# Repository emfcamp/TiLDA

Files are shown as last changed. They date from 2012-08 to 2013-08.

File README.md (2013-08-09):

TiLDA documentation
===================

This repository contains documentation, schematics, and libraries for use with TiLDA.
For example code, see the smaller "source" submodule.

Guides
======

* [Archived docs from 2012](http://wiki-archive.emfcamp.org/2012/articles/b/a/d/Badge.html)
* [Example source code](https://github.com/emfcamp/TiLDA-source)

* [Arduino Guide](http://arduino.cc/en/Guide/ArduinoLeonardo)
* [Getting started with the nRF24L01+](http://maniacbug.wordpress.com/2011/11/02/getting-started-rf24/)

Initialising
------------

    git clone --recursive https://github.com/emfcamp/TiLDA

or

    git clone git@github.com:emfcamp/TiLDA
    cd TiLDA
    git submodule update --init

For building instructions, please see the sample source submodule:

* [TiLDA-source](https://github.com/emfcamp/TiLDA-source)

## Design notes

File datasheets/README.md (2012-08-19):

Hardware
========

* [ATmega32U4](http://www.atmel.com/Images/7766s.pdf) processor
* [Arduino Leonardo](http://arduino.cc/en/Main/arduinoBoardLeonardo)

* [MCP73831](http://ww1.microchip.com/downloads/en/DeviceDoc/21984e.pdf) battery controller
* [GP1UX311QS](http://www.adafruit.com/datasheets/GP1UX31QS.pdf) IR receiver
* [TSAL5100](http://www.vishay.com/doc?81007) IR transmitter
* [nRF24L01+](http://www.nordicsemi.com/kor/content/download/2726/34069/file/nRF24L01P_Product_Specification_1_0.pdf) 2.4GHz transceiver
* [nRF240L01+ module](http://dlnmh9ip6v2uc.cloudfront.net/datasheets/Wireless/Nordic/nRF24L01-Chip-v12.pdf) same pinout, but slightly different module

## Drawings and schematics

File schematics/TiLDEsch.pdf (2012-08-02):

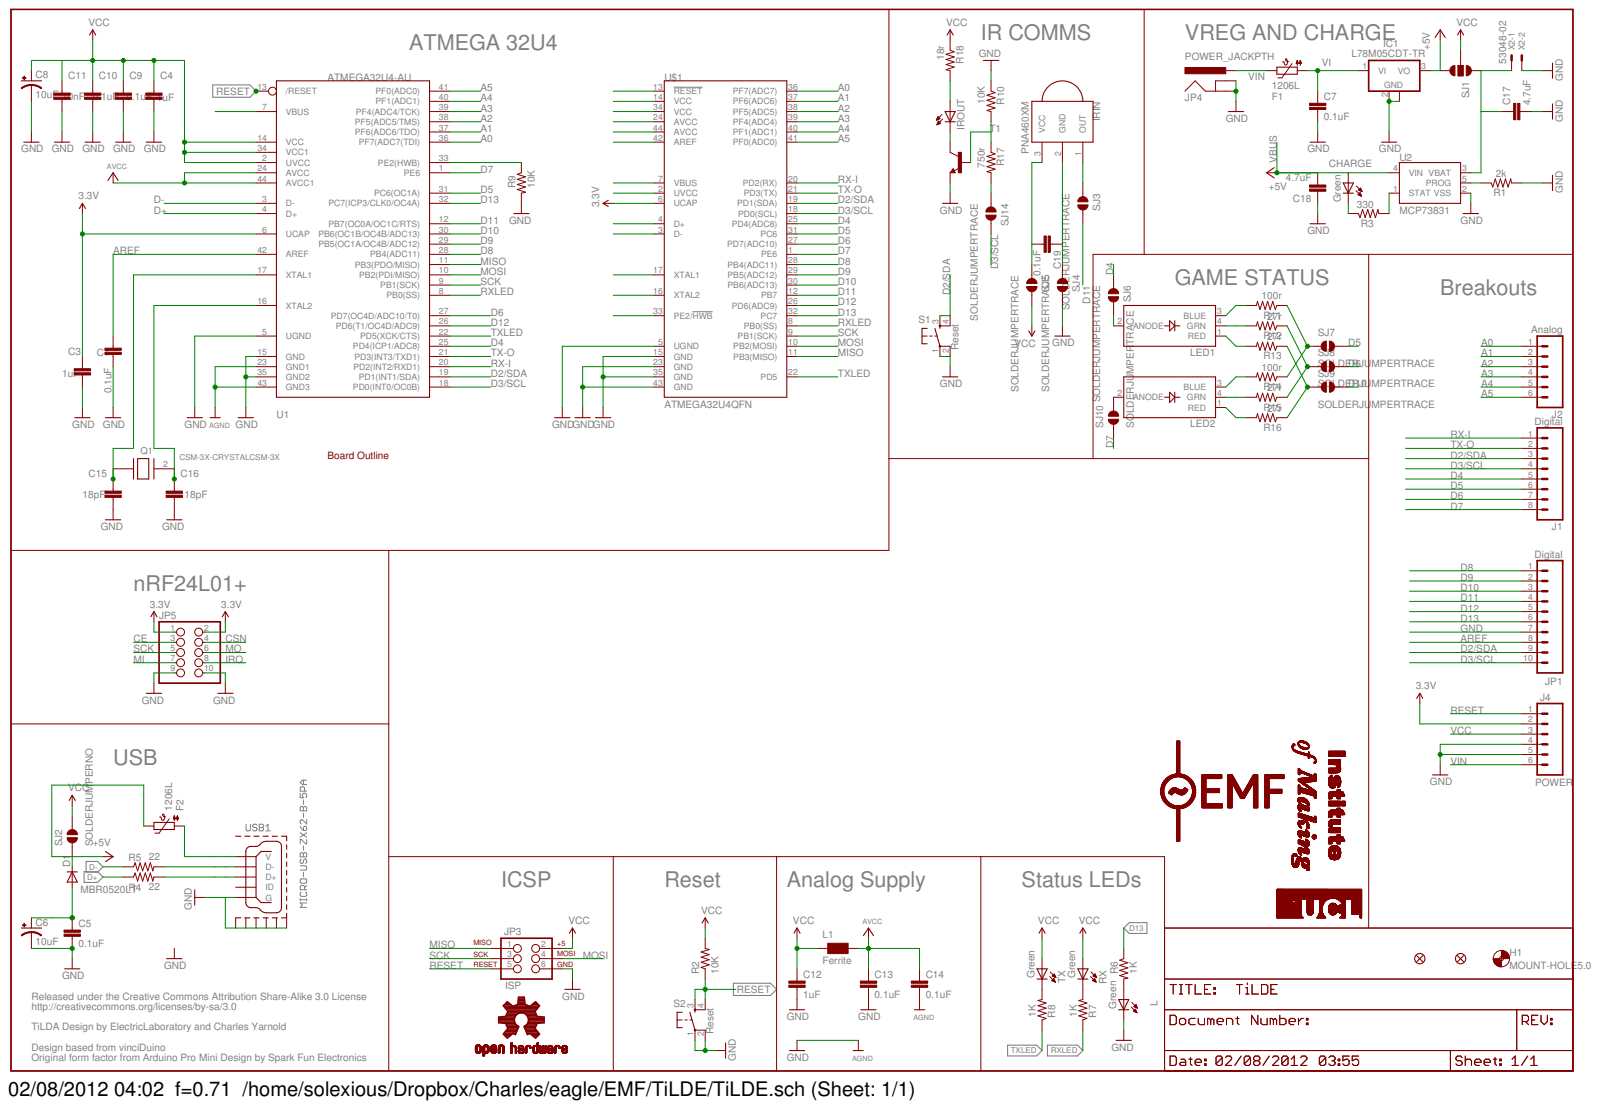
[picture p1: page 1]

GND
Released under the Creative Commons Attribution Share-Alike 3.0 License
http://creativecommons.org/licenses/by-sa/3.0 Original form factor from Arduino Pro Mini Design by Spark Fun Electronics
TiLDA Design by ElectricLaboratory and Charles Yarnold
Design based from vinciDuino
02/08/2012 04:02 f=0.71 /home/solexious/Dropbox/Charles/eagle/EMF/TiLDE/TiLDE.sch (Sheet: 1/1)

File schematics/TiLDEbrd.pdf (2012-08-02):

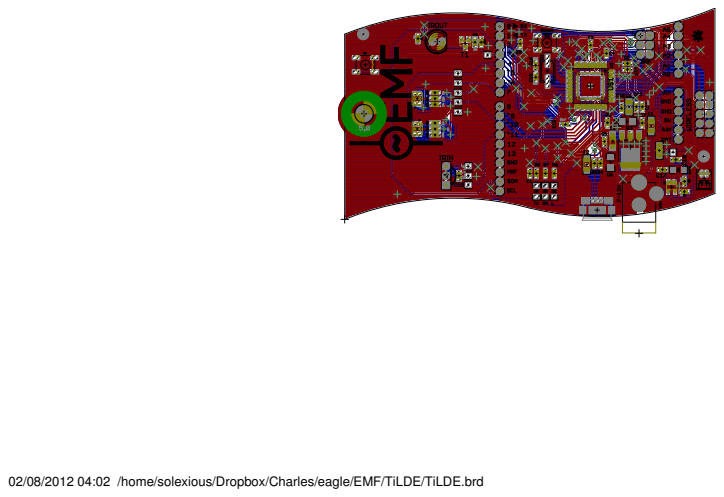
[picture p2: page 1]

02/08/2012 04:02 /home/solexious/Dropbox/Charles/eagle/EMF/TiLDE/TiLDE.brd

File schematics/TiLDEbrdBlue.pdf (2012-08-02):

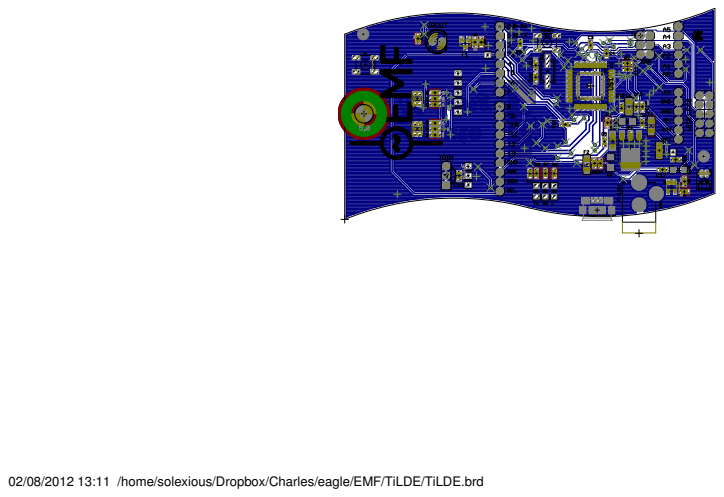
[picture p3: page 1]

02/08/2012 13:11 /home/solexious/Dropbox/Charles/eagle/EMF/TiLDE/TiLDE.brd

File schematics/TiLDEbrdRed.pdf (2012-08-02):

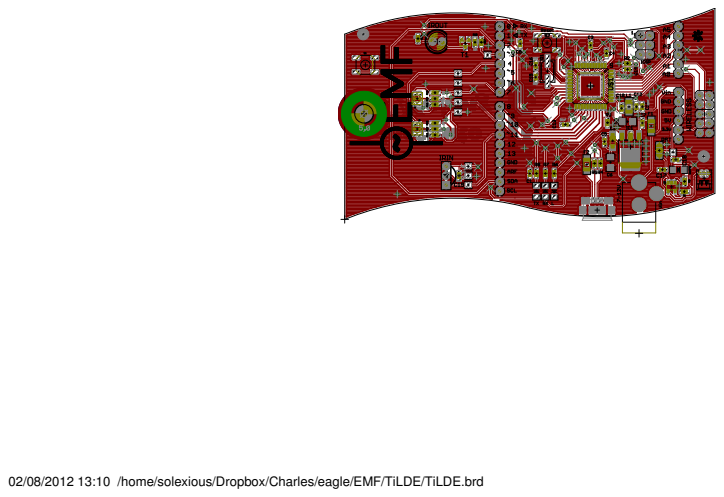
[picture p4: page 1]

02/08/2012 13:10 /home/solexious/Dropbox/Charles/eagle/EMF/TiLDE/TiLDE.brd

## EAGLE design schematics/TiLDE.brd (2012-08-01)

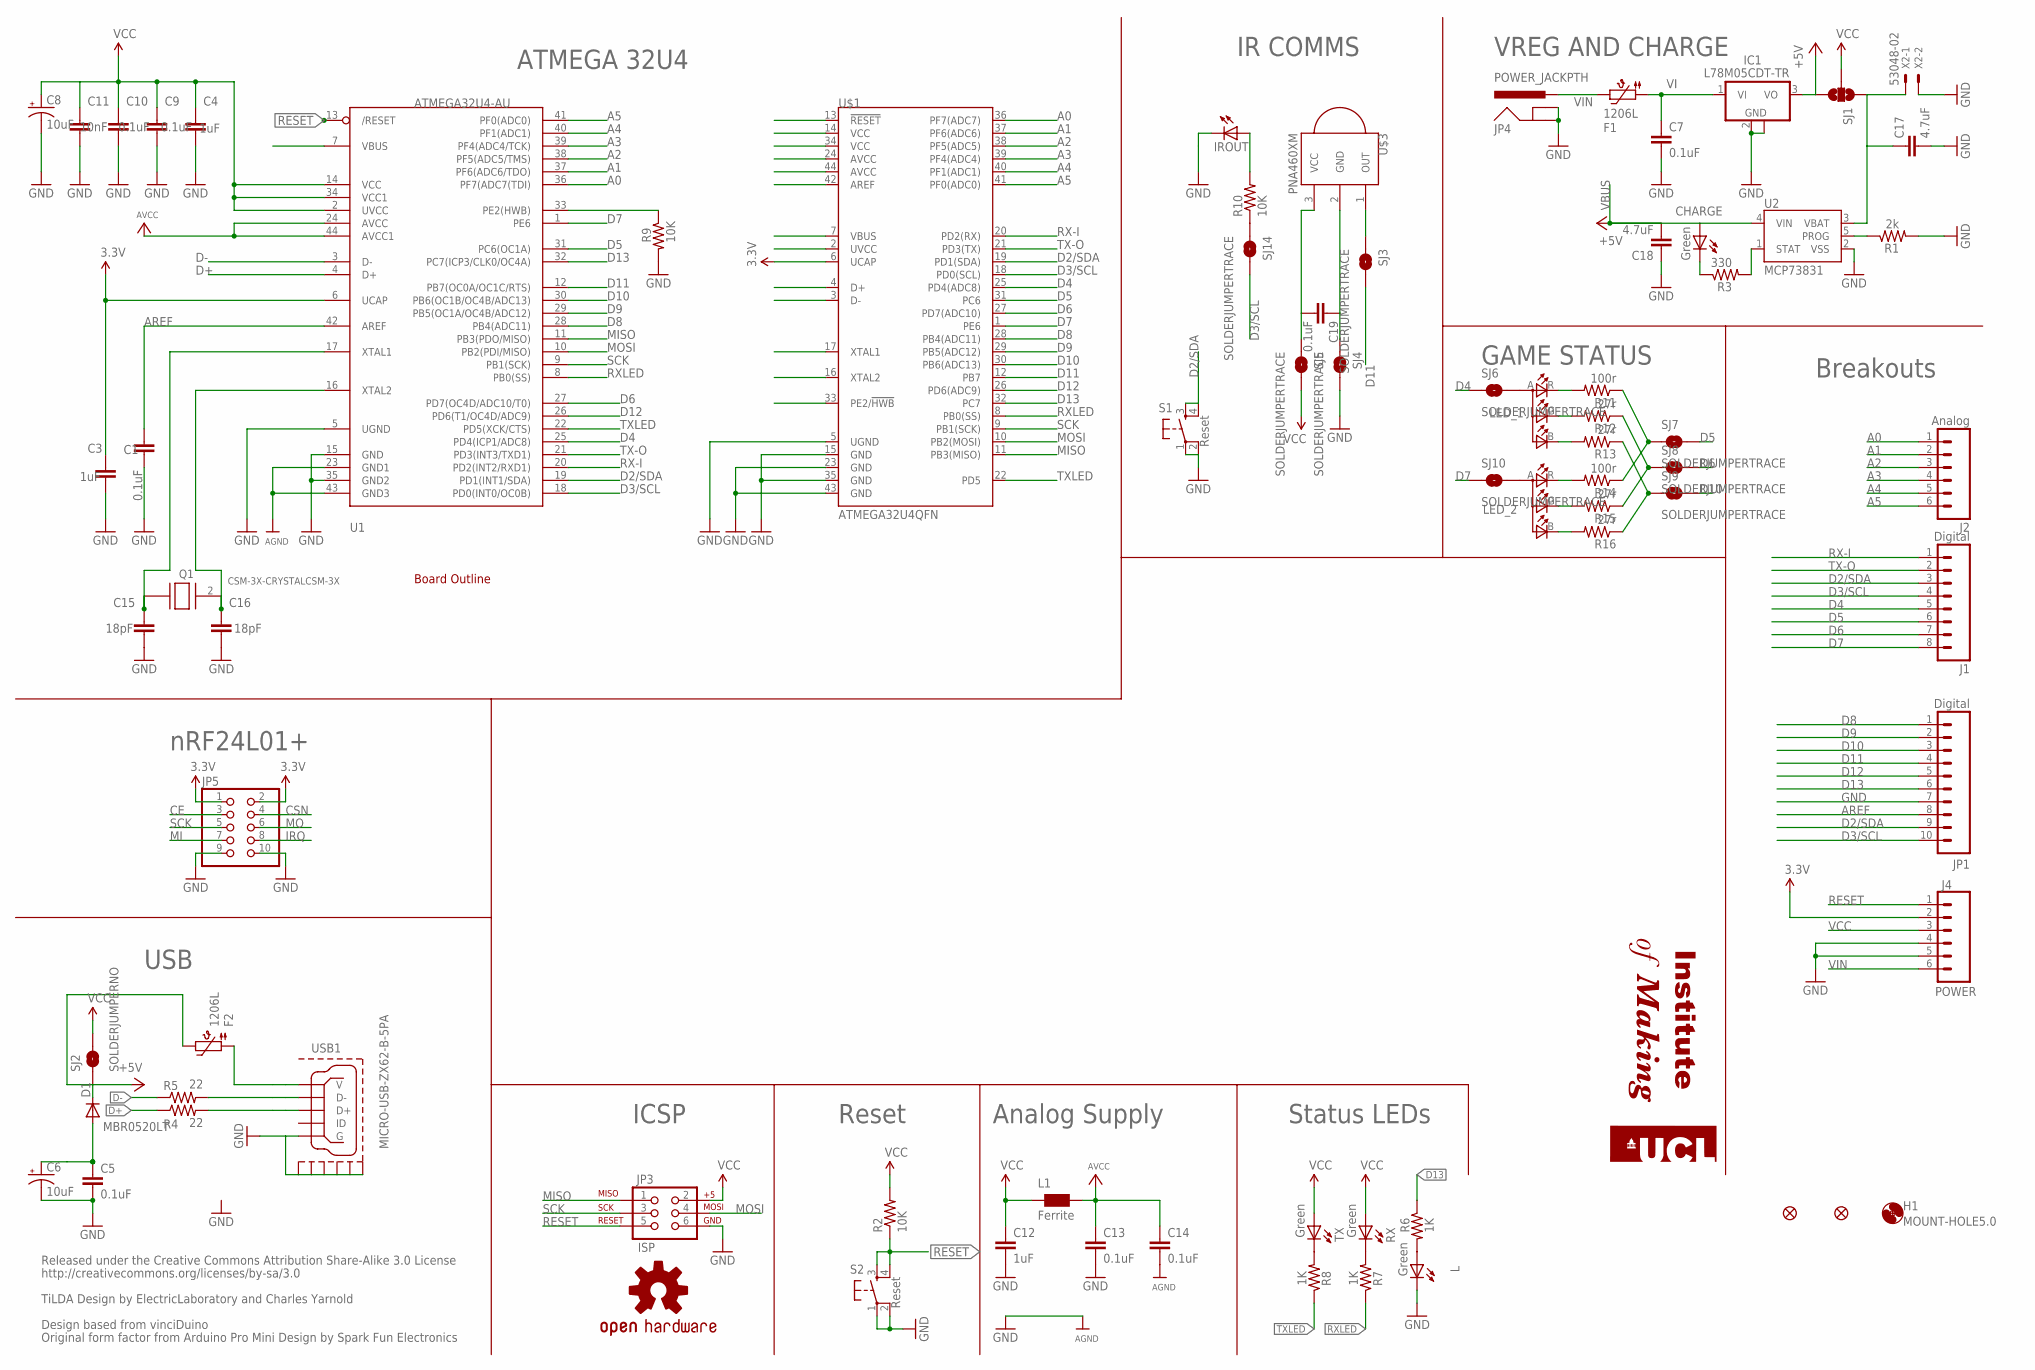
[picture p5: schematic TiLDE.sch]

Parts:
C1, C5, C7, C9, C10, C13, C14, C19: 0.1uF; C0603K
C3, C4, C12: 1uF; C0603K
C6, C8: 10uF; EIA3216
C11: 10nF; C0603K
C15, C16: 18pF; C0603K
C17, C18: 4.7uF; C0603K
CHARGE: Green; LED-1206
D1: MBR0520LT; SOD123
F1, F2: 1206L; 1206_PTC
H1: MOUNT-HOLE5.0; 5,0
IC1: L78M05CDT-TR; SOT-223-DPAK
IROUT: LED5MM
J1: Digital; 1X08
J2: Analog; 1X06
J4: POWER; 1X06
JP1: Digital; 1X10
JP2, JP6: FIDUCIAL1X2.5; FIDUCIAL-1X2.5
JP3: ISP; 2X3
JP4: POWER_JACKPTH; POWER_JACK_PTH
JP5: PINHD-2X5; 2X05
L: Green; LED-1206
L1: Ferrite; 1206W
LED_1, LED_2: CLV1A-FKB
Q1: CSM-3X-CRYSTALCSM-3X; CSM-3X
R1: 2k; 0603-RES
R2, R9, R10: 10K; 0603-RES
R3: 330; 0603-RES
R4, R5: 22; 0603-RES
R6, R7, R8: 1K; 0603-RES
R11, R14: 100r; 0603-RES
R12, R13, R15, R16: 27r; 0603-RES
RX: Green; LED-1206
S1, S2: Reset; TACTILE_SWITCH_SMD
SJ1: SOLDERJUMPER_2WAYT; SJ_2
SJ2: SOLDERJUMPERNO; SJ_2S-NO
SJ3, SJ4, SJ5, SJ6, SJ7, SJ8, SJ9, SJ10, SJ14: SOLDERJUMPERTRACE; SJ_2S-TRACE
TX: Green; LED-1206
U1: ATMEGA32U4-AU; TQFP44
U2: MCP73831; SOT23-5
U$1: ATMEGA32U4QFN; QFN-44
U$2: UCL-LOGO
U$3: PNA460XM
U$5: BOARDOUTLINE; BADGEBOARDBARE
U$14: OSHW-LOGOS; OSHW-LOGO-S
USB1: MICRO-USB-ZX62-B-5PA; ZX62-B-5PA
X2: 53048-02

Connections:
3.3V: C3.1, J4.2, JP5.1, JP5.2, U1.6 (UCAP), U$1.6 (UCAP)
+5V: IC1.3 (VO), SJ1.3
A0: J2.1, JP5.3, U1.36 (PF7(ADC7(TDI)), U$1.36 (PF7(ADC7))
A1: J2.2, JP5.4, U1.37 (PF6(ADC6/TDO)), U$1.37 (PF6(ADC6))
A2: J2.3, U1.38 (PF5(ADC5/TMS)), U$1.38 (PF5(ADC5))
A3: J2.4, U1.39 (PF4(ADC4/TCK)), U$1.39 (PF4(ADC4))
A4: J2.5, U1.40 (PF1(ADC1)), U$1.40 (PF1(ADC1))
A5: J2.6, U1.41 (PF0(ADC0)), U$1.41 (PF0(ADC0))
AREF: C1.2, JP1.8, U1.42 (AREF), U$1.42 (AREF)
AVCC: C13.1, C14.1, L1.2, U1.24 (AVCC), U1.44 (AVCC1), U$1.24 (AVCC), U$1.44 (AVCC)
D2: JP5.8
D2/SDA: J1.3, JP1.9, S1.3, S1.4, U1.19 (PD1(INT1/SDA)), U$1.19 (PD1(SDA))
D3/SCL: J1.4, JP1.10, SJ14.2, U1.18 (PD0(INT0/OC0B)), U$1.18 (PD0(SCL))
D4: J1.5, SJ6.1, U1.25 (PD4(ICP1/ADC8)), U$1.25 (PD4(ADC8))
D5: J1.6, SJ7.2, U1.31 (PC6(OC1A)), U$1.31 (PC6)
D6: J1.7, SJ8.2, U1.27 (PD7(OC4D/ADC10/T0)), U$1.27 (PD7(ADC10))
D7: J1.8, SJ10.1, U1.1 (PE6), U$1.1 (PE6)
D8: JP1.1, U1.28 (PB4(ADC11)), U$1.28 (PB4(ADC11))
D9: JP1.2, U1.29 (PB5(OC1A/OC4B/ADC12)), U$1.29 (PB5(ADC12))
D10: JP1.3, SJ9.2, U1.30 (PB6(OC1B/OC4B/ADC13)), U$1.30 (PB6(ADC13))
D11: JP1.4, SJ3.2, U1.12 (PB7(OC0A/OC1C/RTS)), U$1.12 (PB7)
D12: JP1.5, U1.26 (PD6(T1/OC4D/ADC9)), U$1.26 (PD6(ADC9))
D13: JP1.6, R6.1, U1.32 (PC7(ICP3/CLK0/OC4A)), U$1.32 (PC7)
D+: R4.1, U1.4 (D+), U$1.4 (D+)
D-: R5.1, U1.3 (D-), U$1.3 (D-)
GND: C1.1, C3.2, C4.2, C5.2, C6.C (-), C7.2, C8.C (-), C9.2, C10.2, C11.2, C12.2, C13.2, C14.2, C15.2, C16.2, C17.2, C18.1, IC1.2 (GND), IC1.4 (GND), IROUT.K (C), J4.4, J4.5, JP1.7, JP3.6, JP4.GND, JP4.GNDBREAK, JP5.9, JP5.10, L.C, R1.2, R9.2, S1.1, S1.2, S2.1, S2.2, SJ4.2, U1.5 (UGND), U1.15 (GND), U1.23 (GND1), U1.35 (GND2), U1.43 (GND3), U2.2 (VSS), U$1.5 (UGND), U$1.15 (GND), U$1.23 (GND), U$1.35 (GND), U$1.43 (GND), USB1.5 (G), USB1.GND@1 (GND1), USB1.GND@2 (GND2), USB1.GND@3 (GND3), USB1.GND@4 (GND4), USB1.GND@5 (GND5), USB1.GND@6 (GND6), X2.2
HWB: R9.1, U1.33 (PE2(HWB)), U$1.33 (PE2/!HWB)
MISO: JP3.1, JP5.7, U1.11 (PB3(PDO/MISO)), U$1.11 (PB3(MISO))
MOSI: JP3.4, JP5.6, U1.10 (PB2(PDI/MISO)), U$1.10 (PB2(MOSI))
unnamed: R8.2, TX.C
unnamed: R5.2, USB1.2 (D-)
unnamed: C19.1, SJ4.1, U$3.2 (GND)
unnamed: C19.2, SJ5.1, U$3.3 (VCC)
unnamed: R4.2, USB1.3 (D+)
unnamed: SJ3.1, U$3.1 (OUT)
unnamed: L.A, R6.2
unnamed: C17.1, SJ1.1, U2.3 (VBAT), X2.1
unnamed: R7.2, RX.C
unnamed: R1.1, U2.5 (PROG)
unnamed: R3.2, U2.1 (STAT)
unnamed: CHARGE.C, R3.1
unnamed: F2.1, USB1.1 (V)
unnamed: LED_1.R (CRED), R11.2
unnamed: LED_1.G (CGREEN), R12.2
unnamed: LED_1.B (CBLUE), R13.2
unnamed: LED_2.R (CRED), R14.2
unnamed: LED_2.G (CGREEN), R15.2
unnamed: LED_2.B (CBLUE), R16.2
unnamed: R11.1, R14.1, SJ7.1
unnamed: R12.1, R15.1, SJ8.1
unnamed: R13.1, R16.1, SJ9.1
unnamed: LED_2.A (ANODE), SJ10.2
unnamed: C5.1, C6.A (+), D1.A
unnamed: LED_1.A (ANODE), SJ6.2
unnamed: R10.1, SJ14.1
unnamed: IROUT.A, R10.2
RESET: J4.1, JP3.5, R2.1, S2.3, S2.4, U1.13 (/RESET), U$1.13 (!RESET)
RX-I: J1.1, U1.20 (PD2(INT2/RXD1)), U$1.20 (PD2(RX))
RXLED: R7.1, U1.8 (PB0(SS)), U$1.8 (PB0(SS))
SCK: JP3.3, JP5.5, U1.9 (PB1(SCK)), U$1.9 (PB1(SCK))
TX-O: J1.2, U1.21 (PD3(INT3/TXD1)), U$1.21 (PD3(TX))
TXLED: R8.1, U1.22 (PD5(XCK/CTS)), U$1.22 (PD5)
VBUS: C18.2, CHARGE.A, D1.C, F2.2, SJ2.1, U1.7 (VBUS), U2.4 (VIN), U$1.7 (VBUS)
VCC: C4.1, C8.A (+), C9.1, C10.1, C11.1, C12.1, J4.3, JP3.2, L1.1, R2.2, RX.A, SJ1.2, SJ2.2, SJ5.2, TX.A, U1.2 (UVCC), U1.14 (VCC), U1.34 (VCC1), U$1.2 (UVCC), U$1.14 (VCC), U$1.34 (VCC)
VI: C7.1, F1.1, IC1.1 (VI)
VIN: F1.2, J4.6, JP4.PWR
XTAL1: C15.1, Q1.1, U1.17 (XTAL1), U$1.17 (XTAL1)
XTAL2: C16.1, Q1.2, U1.16 (XTAL2), U$1.16 (XTAL2)

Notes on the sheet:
Released under the Creative Commons Attribution Share-Alike 3.0 License
http://creativecommons.org/licenses/by-sa/3.0
Original form factor from Arduino Pro Mini Design by Spark Fun Electronics
USB
Reset
ICSP
Analog Supply
Status LEDs
Breakouts
ATMEGA 32U4
Design based from vinciDuino
VREG AND CHARGE
SCK
CSN
IRQ
nRF24L01+
IR COMMS
GAME STATUS
TiLDA Design by ElectricLaboratory and Charles Yarnold
VBUS

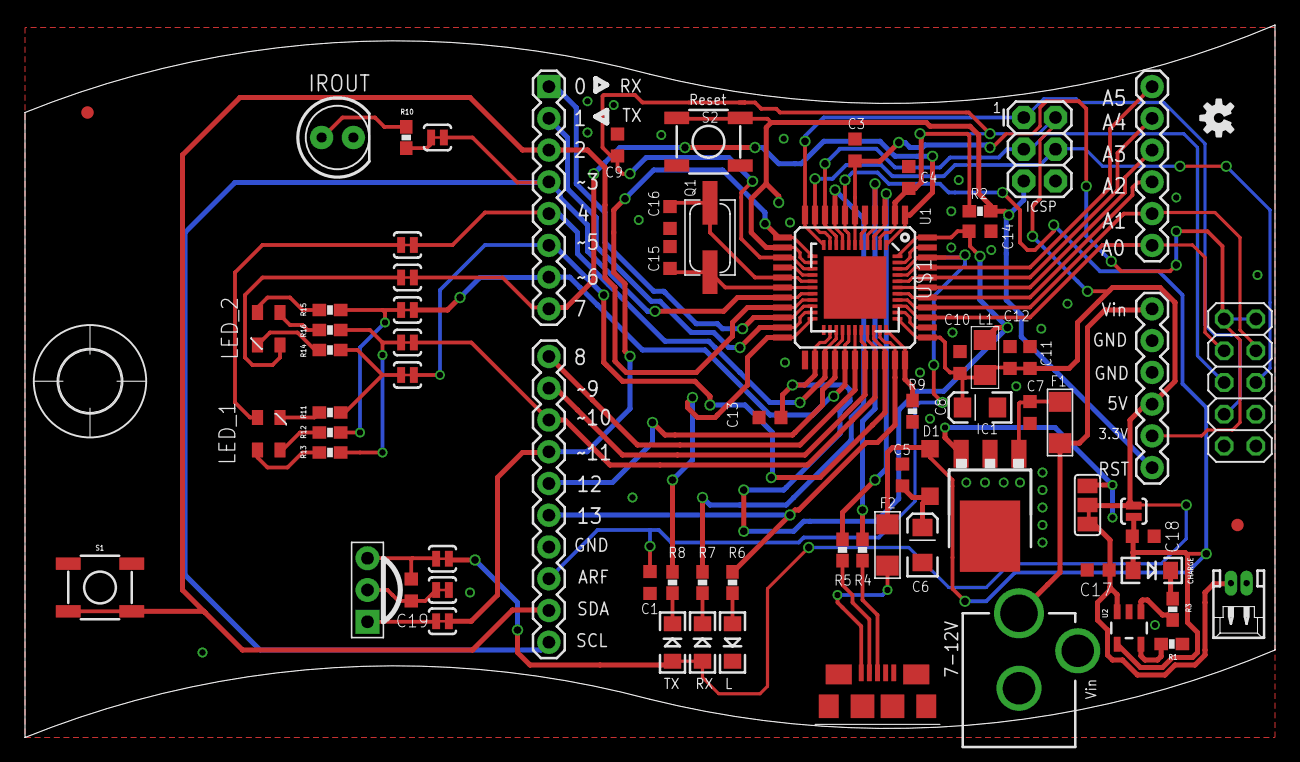
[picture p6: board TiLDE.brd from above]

Board: 2 copper layers, 100.0 x 57.0 mm, 79 parts (1 on the bottom side), 67 nets.

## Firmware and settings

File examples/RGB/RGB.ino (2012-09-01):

#include "lights.h"
#include "pins.h"

Lights lights;

unsigned long last_button_down = 0;
bool torch_on = false;

bool check_torch_mode(int state) {
  if (state == LOW) { // Low means pressed
    led_stop_cycle();
    last_button_down = millis();
  } else {
    if (last_button_down != 0 && last_button_down < millis() - 1000) {
      // Engage torch mode
      lights.set(PIN_LED_BOTH, 255, 255, 255);
      torch_on = true;
      return true;
    }
    if (torch_on) {
      lights.set(PIN_LED_BOTH, 0, 0, 0);
      torch_on = false;
      return true;
    }
  }
  return false;
}

void button_press() {
  // Interrupt handler when button state changes
  int state = digitalRead(PIN_BUTTON);
  if (check_torch_mode(state)) {  
    return;
  }
}

void setup() {
  pinMode(PIN_IR_OUT, OUTPUT);
  pinMode(PIN_BUTTON, INPUT_PULLUP);
  attachInterrupt(INT_BUTTON, button_press, CHANGE);
}

void loop() {
  if(!torch_on) {
    led_cycle(&lights, PIN_LED_BOTH, 1000);
    lights.set(PIN_LED_BOTH, 0, 0, 0);
  } else {
    led_stop_cycle();
  }
}

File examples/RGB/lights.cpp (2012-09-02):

#include "lights.h"

int pins[] = {PIN_LED_RIGHT, PIN_LED_LEFT, PIN_LED_BLUE, PIN_LED_GREEN, PIN_LED_RED};

// Calibration for LED colour issues
const float calibration[] = {1, 1, 1};
bool led_stop = false;

Lights::Lights() {
  for (int i = 0; i < 6; i++) {
      pinMode(pins[i], OUTPUT);
      digitalWrite(pins[i], HIGH);
  }
}

unsigned logScale(float value) {
  return (unsigned char)((log(255 - value) / log(255)) * 255);
}

void Lights::set(int light, unsigned char red, unsigned char green, unsigned char blue) {
  analogWrite(PIN_LED_RED, logScale(red * calibration[0]));
  analogWrite(PIN_LED_GREEN, logScale(green * calibration[1]));
  analogWrite(PIN_LED_BLUE, logScale(blue * calibration[2]));
  if (light == PIN_LED_RIGHT) {
    digitalWrite(PIN_LED_RIGHT, HIGH);
    digitalWrite(PIN_LED_LEFT, LOW);
  } else if (light == PIN_LED_LEFT) {
    digitalWrite(PIN_LED_LEFT, HIGH);
    digitalWrite(PIN_LED_RIGHT, LOW);
  } else if (light == PIN_LED_BOTH) {
    digitalWrite(PIN_LED_LEFT, HIGH);
    digitalWrite(PIN_LED_RIGHT, HIGH);
  }
}

void led_cycle(Lights *lights, int light, int time) {
  unsigned char red = 0, green = 0, blue = 0;
  unsigned char brightness = 128;
  float step = (2 * PI) / time;
  for (float i = 0; i < 2 * PI; i += step) {
    red = (unsigned char)(abs(sin(i)) * brightness);
    green = (unsigned char)(abs(sin(i + PI / 4)) * brightness);
    blue = (unsigned char)(abs(sin(i + PI / 2)) * brightness);
    if(led_stop) {
      led_stop = false;
      break;
    }
    lights->set(light, red, green, blue);
    delay(1);
  }
}

void led_stop_cycle() {
  led_stop = true;
}

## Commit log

2012-07-22 Add printouts
2012-07-26 change usb, fix silk screen, add ucl logo
    [TiLDE.brd, TiLDE.sch]
2012-07-29 fix wireless MO and MI, remove un needed reset cap
    [TiLDE.brd, TiLDE.sch]
2012-08-01 Fix routing under crystal
    [TiLDE.brd]
2012-08-19 Create schematics subdirectory
    [TiLDE.brd, TiLDE.sch]
2012-08-25 Using arduino.mk for now
2012-09-02 Removing red calibration, seems to stop red working
2012-09-02 Modded lights lib to add non-blocking led_cycle
2012-09-02 make client peer to peer and poll for the button instead of using interrupts
2012-09-02 Changed the calibration, this fixes the chroma example
    [lights.cpp]

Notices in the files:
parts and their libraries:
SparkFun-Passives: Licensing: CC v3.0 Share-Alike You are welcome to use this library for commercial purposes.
